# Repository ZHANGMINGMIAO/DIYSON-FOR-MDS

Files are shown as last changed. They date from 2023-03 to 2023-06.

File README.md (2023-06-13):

# DIYSON-FOR-MDS
复刻戴森台灯

电路连接框图 (2)
电路连接框图 1 (1)

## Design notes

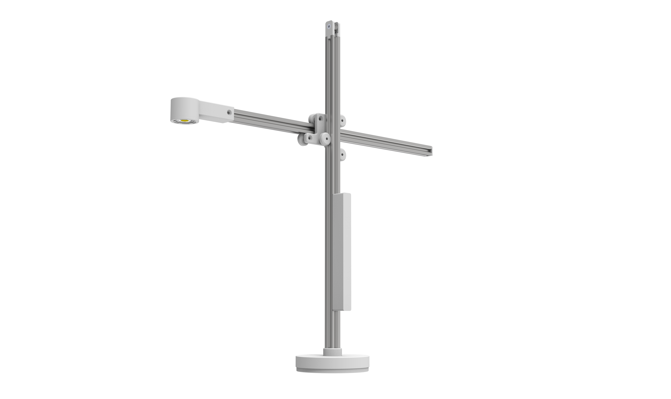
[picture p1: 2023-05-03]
DIYSON V2.png

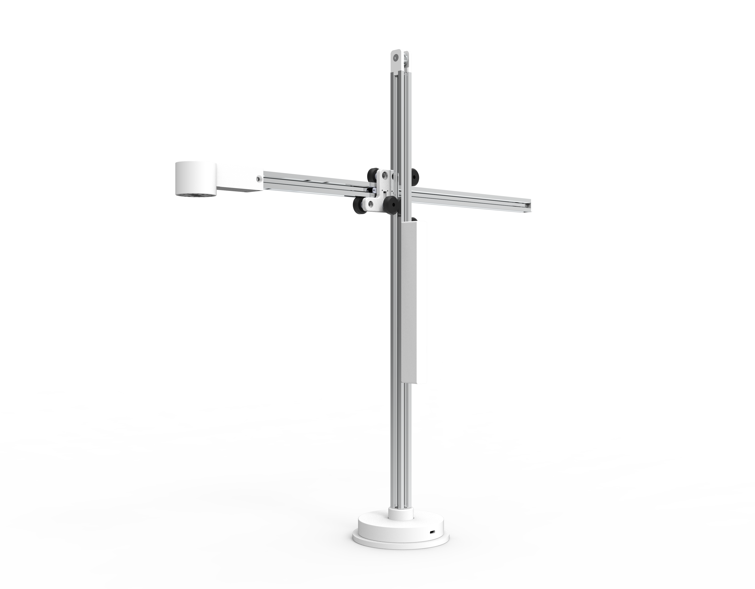
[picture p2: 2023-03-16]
Picture/untitled.3.png

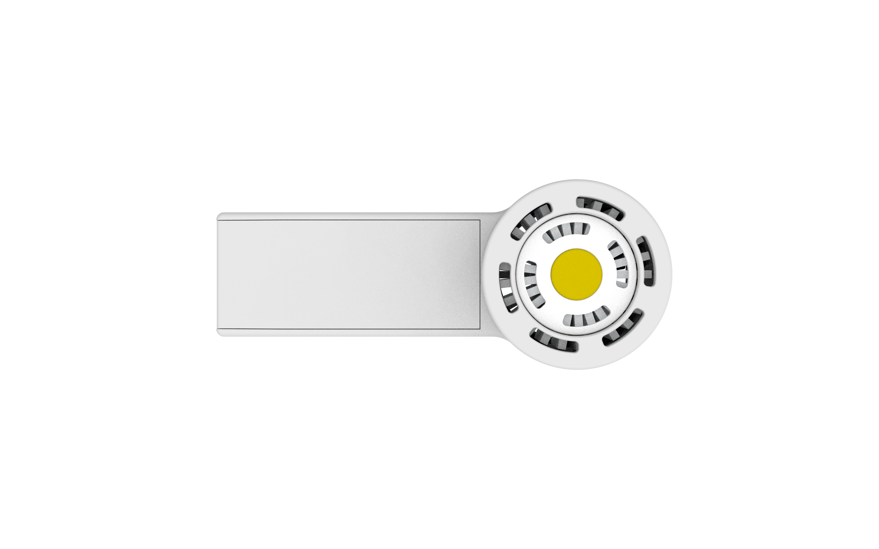
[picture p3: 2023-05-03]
Picture/灯头.7.png

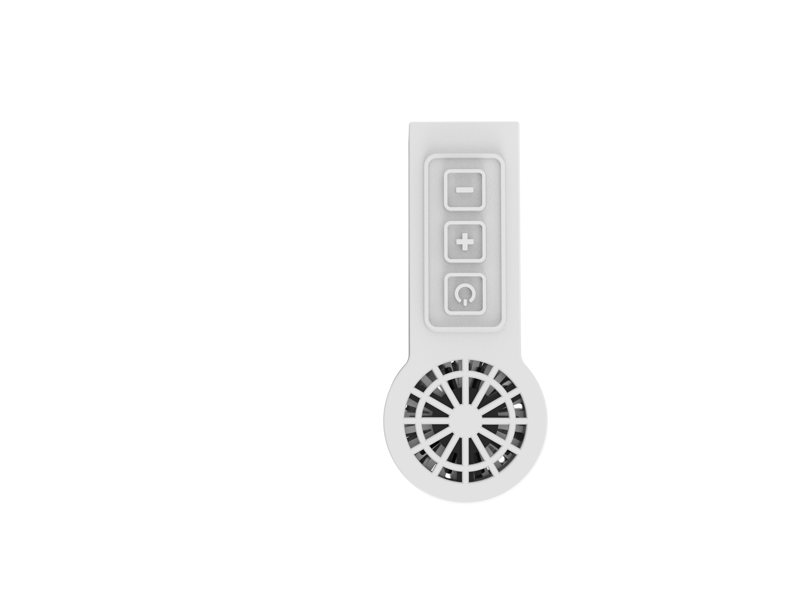
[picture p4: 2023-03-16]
Picture/untitled.5.png

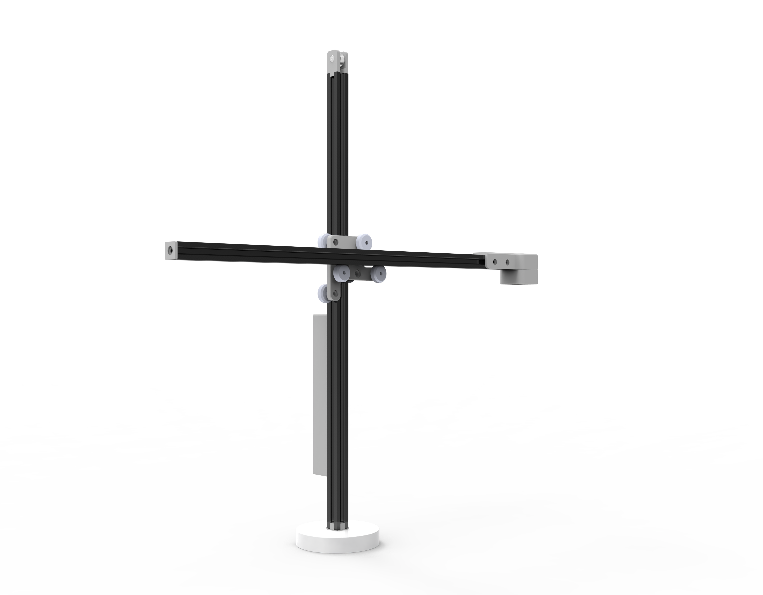
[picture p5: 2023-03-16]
Picture/DIYSON.1.png

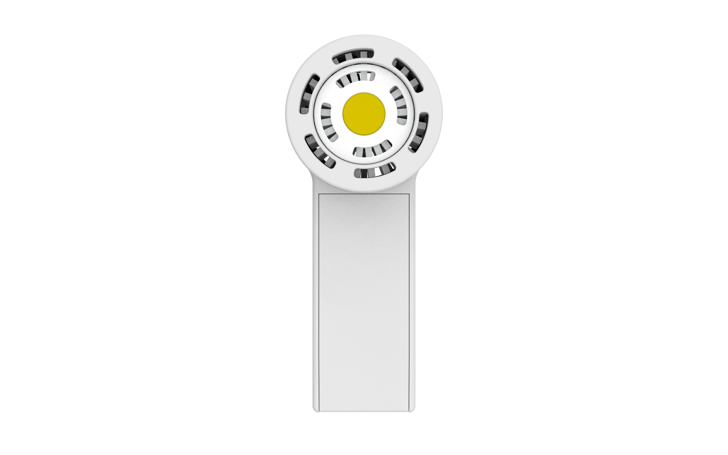
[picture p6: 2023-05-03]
Picture/灯头.9.png

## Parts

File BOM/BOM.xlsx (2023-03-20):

模块 | 元件类型 | 使用量 | 最低购买量 | 价格 | 购买链接
灯头 | CXA1507 4000K 36V 12W灯珠 | 1 | 1 | 7.4 | https://item.taobao.com/item.htm?spm=a1z0d.6639537/tb.1997196601.78.70727484ZepRym&id=674402505086
 | 科锐CREE光源支架COB CXA1507 | 1 | 1 | 1.27 | https://item.taobao.com/item.htm?spm=a1z0d.6639537/tb.1997196601.88.70727484ZepRym&id=38875948747
 | COB灯珠散热器 长度：2CM 直径3.8CM | 1 | 1 | 2.6 | https://item.taobao.com/item.htm?spm=a1z09.2.0.0.199f2e8dHjGU9n&id=651109740128&_u=j29jqmml1d36
 | LED透镜COB灯珠超薄透镜 35*12 | 1 | 1 | 0.8 | https://item.taobao.com/item.htm?spm=a1z09.2.0.0.199f2e8dHjGU9n&id=628937945428&_u=j29jqmml4557
 | 41*10MM圆形静音5V静音液压4CM风扇 3500rpm | 1 | 1 | 4.2 | https://item.taobao.com/item.htm?spm=a1z09.2.0.0.199f2e8dHjGU9n&id=690257082820&_u=j29jqmmlabdc
 | COB导热硅脂 | 1 | 1 | 1.4 | https://item.taobao.com/item.htm?spm=a1z09.2.0.0.199f2e8dHjGU9n&id=659749305136&_u=j29jqmmlfe73
 | 1.25mm 端子线 2P 双头(同向) | 5 | 10 | 1.95 | https://detail.tmall.com/item.htm?_u=j29jqmmle543&id=624732974819&spm=a1z09.2.0.0.199f2e8dHjGU9n
 | M2.6 自攻螺丝 M2.6 8mm | 2 | 20 | 5.3 | https://detail.tmall.com/item.htm?_u=j29jqmmla5ac&id=668672388165&spm=a1z09.2.0.0.199f2e8dHjGU9n
 | B-7000透明强力胶水 | 1 | 1 | 1.3 | https://item.taobao.com/item.htm?spm=a1z09.2.0.0.199f2e8dHjGU9n&id=651453833277&_u=j29jqmml6029
 | XL6019DC-DC可调升压电源模块 | 1 | 1 | 6.8 | https://detail.tmall.com/item.htm?abbucket=0&id=684608023988&ns=1&spm=a21n57.1.0.0.3d7b523cxRJ48t
 | TTP223触摸传感器触摸按键模块 | 1 | 1 | 2.29 | https://item.taobao.com/item.htm?spm=a1z09.2.0.0.199f2e8dHjGU9n&id=534945488372&_u=j29jqmml50a1
 | AMS1117-3.3V | 1 | 10 | 2.5 | https://item.taobao.com/item.htm?spm=a1z09.2.0.0.61952e8dVH444n&id=592499744957&_u=j29jqmml6740
连接架与底座 | 优质聚氨酯2GT白色同步带带宽6mm | 1 | 1 | 4.63 | https://item.taobao.com/item.htm?spm=a1z09.2.0.0.61952e8dVH444n&id=653571534103&_u=j29jqmmlf75c
 | 电池座手机电池连接器立式 2P 3.5H | 2 | 1 | 0.9 | https://item.taobao.com/item.htm?spm=a1z09.2.0.0.61952e8dVH444n&id=670722052173&_u=j29jqmml61cf
 | 绝缘柱塑料垫片 9*5*6 | 6 | 200 | 6.2 | https://detail.tmall.com/item.htm?_u=j29jqmml6f5f&id=631929683825&spm=a1z09.2.0.0.61952e8dVH444n
 | 3D打印机滑轮 导轨 张紧吊轮大轮 | 6 | 1 | 9 | https://item.taobao.com/item.htm?spm=a1z09.2.0.0.61952e8dVH444n&id=525708632172&_u=j29jqmmlcd35
 | 铁沙0.5/1/2/3/4mm钢砂脚架配重 2.0mm 1KG | 1 | 1 | 9.9 | https://item.taobao.com/item.htm?spm=a1z09.2.0.0.61952e8dVH444n&id=650785697009&_u=j29jqmmld822
 | t型螺母欧标铝型材弹片钢珠滑块 钢珠弹性20型-M5 (20个) 镀镍 | 2 | 20 | 6.8 | https://detail.tmall.com/item.htm?_u=j29jqmml949d&id=595406623302&spm=a1z09.2.0.0.61952e8dVH444n
 | 304不锈钢十字自攻螺丝沉头 M2*8 | 17 | 200 | 4.5 | https://detail.tmall.com/item.htm?_u=j29jqmmla5ac&id=668672388165&skuId=4991019363520
 | 304不锈钢十字自攻螺丝沉头 M2*12 | 6 | 200 | 5.3 | https://detail.tmall.com/item.htm?_u=j29jqmmla5ac&id=668672388165&skuId=4991019363520
 | 日本品牌高速电机静音轴承 206ZZ/P5铁封内径（mm） | 1 | 1 | 13.51 | https://detail.tmall.com/item.htm?_u=j29jqmml9dd1&id=590261283515&skuId=4705909512224
 | PD诱骗器触发QC4笔记本电源改装 12V升级版-PD诱骗器[PDT006] | 1 | 1 | 6.9 | https://item.taobao.com/item.htm?spm=a1z09.2.0.0.61952e8dVH444n&id=591914312564&_u=j29jqmml97ce
 | 2020V槽欧标铝型材2020v-slot铝材 60CM (注：两头攻牙M5螺纹) | 2 | 1 | 20 | https://item.taobao.com/item.htm?spm=a1z09.2.0.0.61952e8dVH444n&id=600111315253&_u=j29jqmmla28d
 | dc电源电源插座直流插头 DC-083插座 3.5-1.3MM | 1 | 5 | 3.5 | https://detail.tmall.com/item.htm?_u=j29jqmml3048&id=666895841322&spm=a1z09.2.0.0.61952e8dVH444n
 | 插头电源插座插头DC-005 DC插头 3.5*1.3 | 1 | 5 | 2.35 | https://detail.tmall.com/item.htm?_u=j29jqmml4f0e&id=667427411705&spm=a1z09.2.0.0.61952e8dVH444n
 | 通孔铜镶嵌注塑螺母预埋件 2*5*3.5 | 6 | 100 | 3 | https://buyertrade.taobao.com/trade/itemlist/list_bought_items.htm
 | 3D打印机配件2GT惰轮 16齿/20齿同步带轮H型皮带轮滑轮带宽6/10MM | 1 | 1 | 2.65 | https://item.taobao.com/item.htm?spm=a1z09.2.0.0.54c52e8dhvQr17&id=548682226471&_u=j29jqmml20ae
 | 12.9沉头内六角合金钢高强度 M5*10MM | 5 | 50 | 4.7 | https://detail.tmall.com/item.htm?_u=j29jqmmlafcb&id=677749487330&skuId=4860920044837
 | 12.9沉头内六角合金钢高强度 M5*25MM | 1 | 50 | 7.8
 | 12.9沉头内六角合金钢高强度 M5*30MM | 6 | 20 | 4.1
 | 304不锈钢尼龙防松螺母 M5 | 6 | 50 | 4.4 | https://detail.tmall.com/item.htm?id=606065145380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
PCB | 触点连接件 厚度1mm 白色阻焊 | 2 | 2 | 20 | 嘉立创PCB，打样文件在PCB文件夹
 | 58.5cm*1.1cm 滑动导轨 PCB厚度 1.2mm 白色阻焊 | 3 | 3 | 68 | 捷配PCB，打样文件在PCB文件夹
3D打印耗材 | 彩格PLA耗材3D打印机材料可定制 PLA 1.75 白色1KG | 1 | 1 | 56.8 | https://detail.tmall.com/item.htm?_u=j29jqmml000b&id=555578272810&spm=a1z09.2.0.0.61952e8dVH444n
 |  |  | 总计： | 302.75

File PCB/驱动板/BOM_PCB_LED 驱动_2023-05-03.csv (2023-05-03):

ID | Name | Designator | Footprint | Quantity | Manufacturer Part | Manufacturer | Supplier | Supplier Part | Price
1 | 22uf 50V | C1,C2,C5,C6 | C0603 | 4 |  |  | LCSC | C94073 | 0.0267
2 | 100nf 50V | C8,C10 | C0603 | 2 |  |  | LCSC | C5199872 | 0.042
3 | 0.51R | R5,R2 | R0603 | 2 |  |  | LCSC | C2073794 | 3.18
4 | 2543U-104CNG1SNT01 | H2 | HDR-TH_4P-P2.00-V-F | 1 | 2543U-104CNG1SNT01 | 华宇创 | LCSC | C350271 | 0.6401
5 | 100nf 50V | C3,C4,C9,C12 | C0603 | 4 |  |  | LCSC | C94073 | 0.0267
6 | 47uF 50V | C7,C15 | CAP-SMD_BD6.3-L6.6-W6.6-LS7.4-FD | 2 |  |  | LCSC | C688950 | 0.8894
7 | 22uf 50V | C13,C16 | C0603 | 2 |  |  | LCSC | C2762594 | 0.3109
8 | 47UH | L1,L2 | IND-SMD_L7.3-W6.6_MHCI06030 | 2 |  |  | LCSC | C5349685 | 0.4365
9 | 4.7UH | L3 | IND-SMD_L10.0-W10.0_MS1040-XX | 1 |  |  | LCSC | C436485 | 1.087
10 | 47K | R7,R9 | R0603 | 2 |  |  | LCSC | C115320 | 0.0049
11 | NC | U6 | HDR-TH_2P-P2.54-V-M-1 | 1 | 单排2.54*2 | null | LCSC | C9900016158
12 | AO3415AL | Q2 | SOT-23-3_L2.9-W1.6-P1.90-LS2.9-BL | 1 | AO3415AL | AOS | LCSC | C181094 | 0.2267
13 | TPS54202DDCR | U4 | SOT-23-6_L2.9-W1.6-P0.95-LS2.8-BR | 1 | TPS54202DDCR | Texas Instruments | LCSC | C191884 | 1.4653
14 | 10kΩ | R10 | RES-ADJ-SMD_3P-L3.0-W3.8-P1.75-BR | 1 | TC33X-2-103E | BOURNS | LCSC | C128547 | 0.557
15 | 100k | R11 | R0603 | 1 |  |  | LCSC | C115320 | 0.0049
16 | 20k | R13 | R0603 | 1 |  |  | LCSC | C125934 | 0.013
17 | 2.7k | R14 | R0603 | 1 |  |  | LCSC | C13167 | 0.0064
18 | 100nf | C14 | C0603 | 1 |  |  | LCSC | C94073 | 0.0267
19 | 10uH | L4 | IND-SMD_L4.0-W4.0_XFL4020-102MEB | 1 | YSPI0530-100M | YJYCOIN | LCSC | C351099 | 0.9762
20 | 56k | R8 | R0603 | 1 |  |  | LCSC | C23206 | 0.0068
21 | SS34BG | D4,D5,D1 | SMB_L4.6-W3.6-LS5.3-RD | 3 | SS34BG | SHIKUES(时科) | LCSC | C2891718 | 0.1679
22 | 3k | R4,R3 | R0603 | 2 |  |  | LCSC | C125893 | 0.013
23 | 1k | R6,R1 | R0603 | 2 |  |  | LCSC | C2982978 | 0.0119
24 | XL6019E1 | U3 | TO-263-5_L10.2-W9.9-P1.70-LS14.4-TL | 1 | XL6019E1 | XLSEMI(芯龙) | LCSC | C73018 | 3.51
25 | HI7003 | U1,U2 | SOP-8 | 2 | HI7003 | Hichips(智芯) | LCSC | C2830170 | 2.97

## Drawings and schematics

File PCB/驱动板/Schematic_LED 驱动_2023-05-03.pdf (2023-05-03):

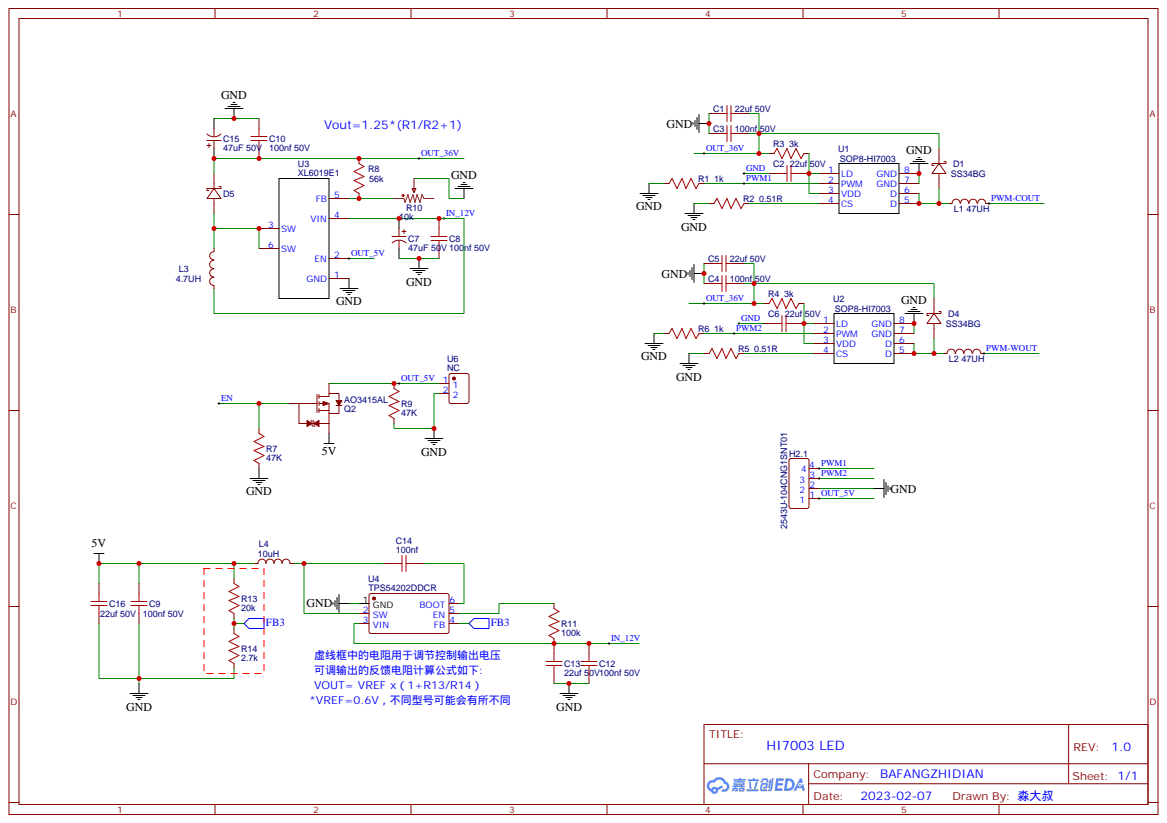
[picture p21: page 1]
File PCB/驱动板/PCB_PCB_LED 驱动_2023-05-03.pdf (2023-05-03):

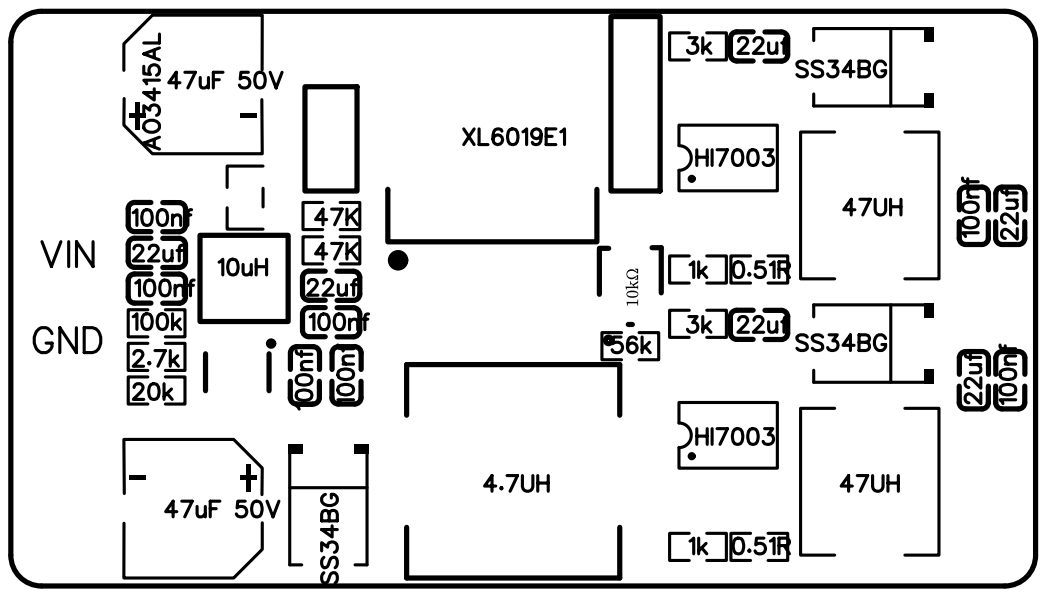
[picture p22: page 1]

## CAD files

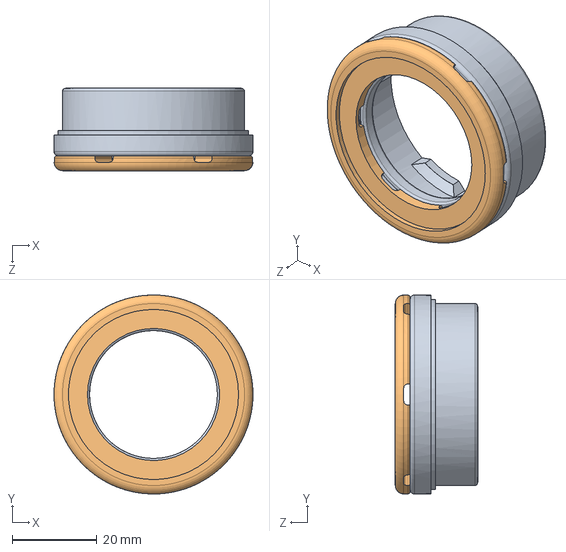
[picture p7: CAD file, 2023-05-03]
slprt/灯头柔光.SLDASM
47.0 x 47.0 x 19.5 mm
灯头盖 - 副本
柔光盖

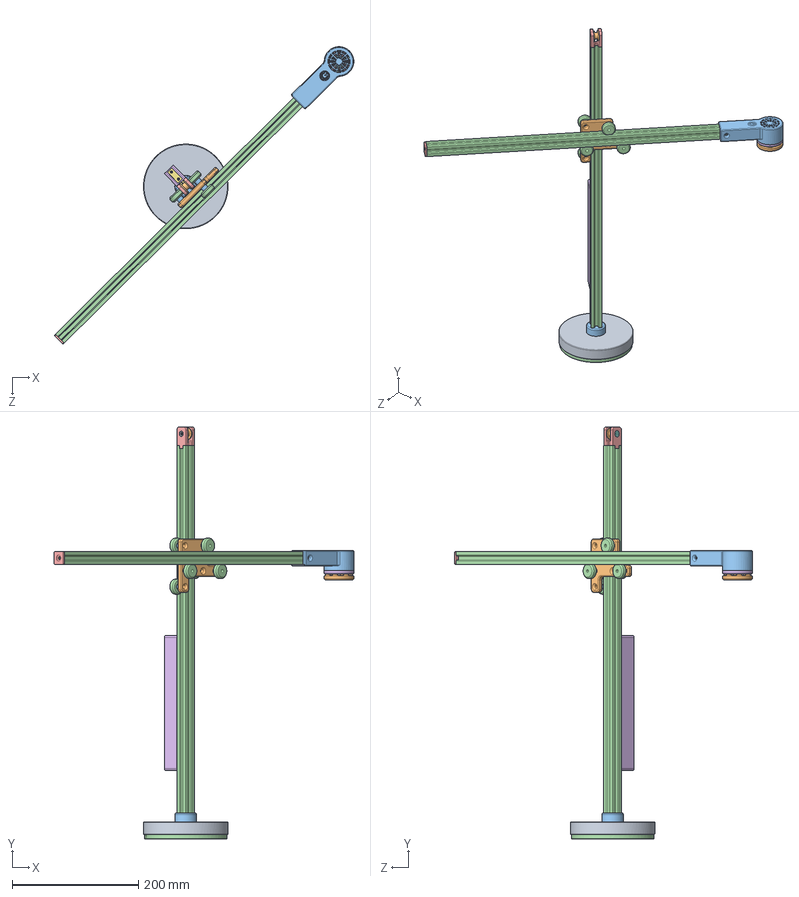
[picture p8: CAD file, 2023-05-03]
slprt/DIYSON.SLDASM
475.2 x 653.2 x 472.0 mm
底座
6206ZZ轴承
Base
2020V 铝型材 x 2
Pulley Mount
Coutnterweight Enclosure
Flex Tab x 2
螺丝^DIYSON
螺母^DIYSON
2GT多轮
隔离柱 x 6
Big wheel x 6
End Cap
Counterweight Belt Clip
Coutnterweight Lid
Base2
DC
Carriage
灯头42
风扇3010
散热器3820
灯头盖
零件2^灯头
零件3^灯头
零件4^灯头
底座盖板2
USB_Type-C

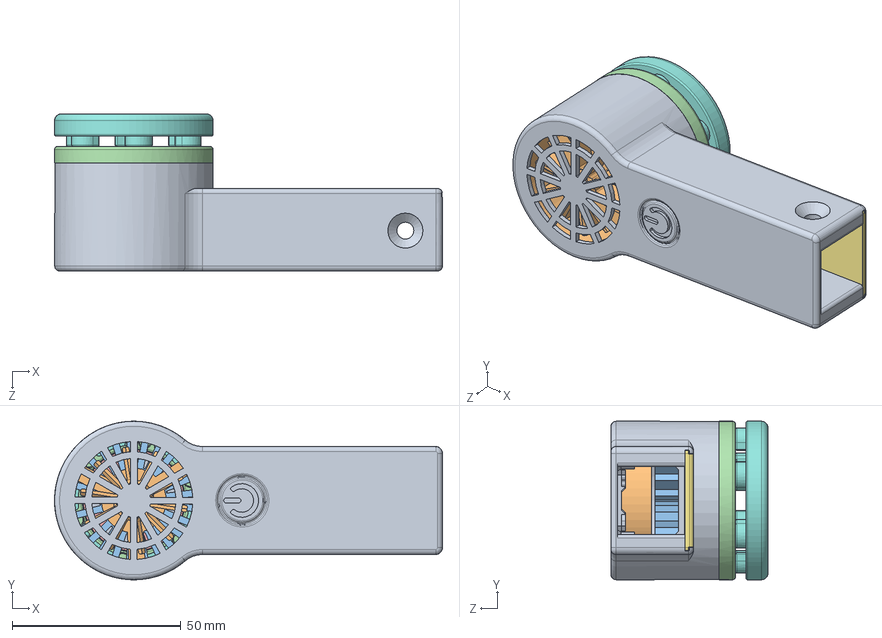
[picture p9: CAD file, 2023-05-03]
slprt/灯头.SLDASM
115.0 x 47.0 x 46.6 mm
灯头42
风扇3010
散热器3820
灯头盖
零件2^灯头
零件3^灯头
零件4^灯头

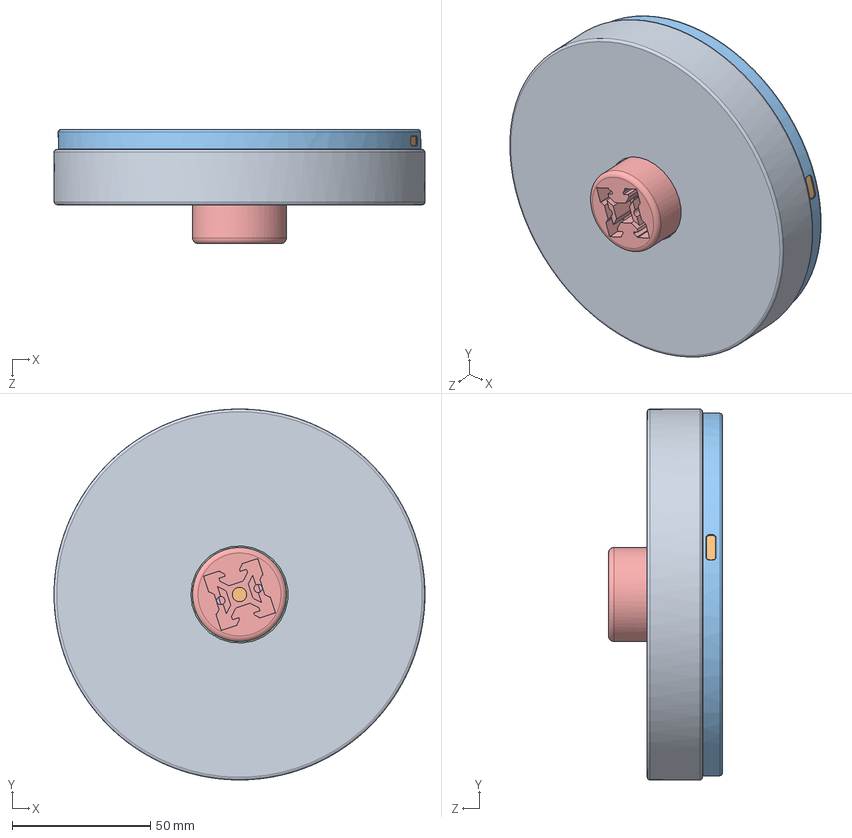
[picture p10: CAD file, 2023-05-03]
slprt/底座.SLDASM
134.0 x 134.0 x 41.2 mm
底座
底座盖板2
6206ZZ轴承
Base
Base2

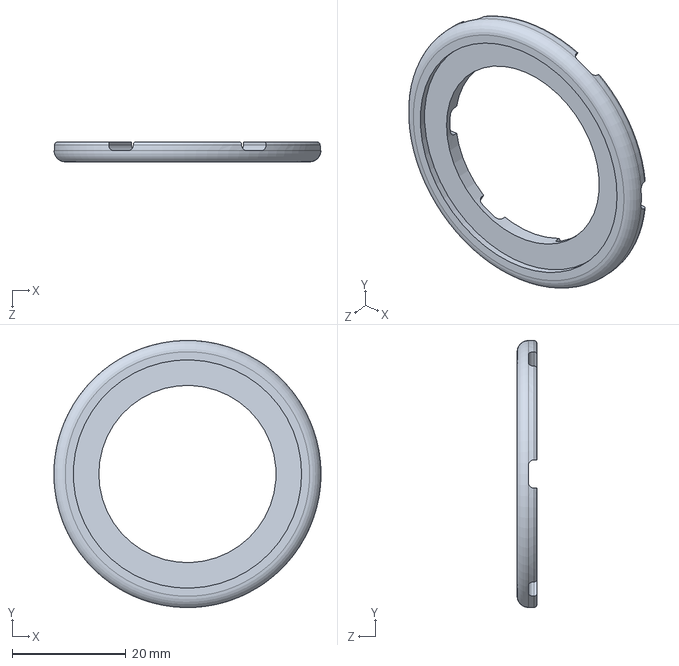
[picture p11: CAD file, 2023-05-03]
slprt/柔光盖.sldprt
47.0 x 47.0 x 3.50 mm

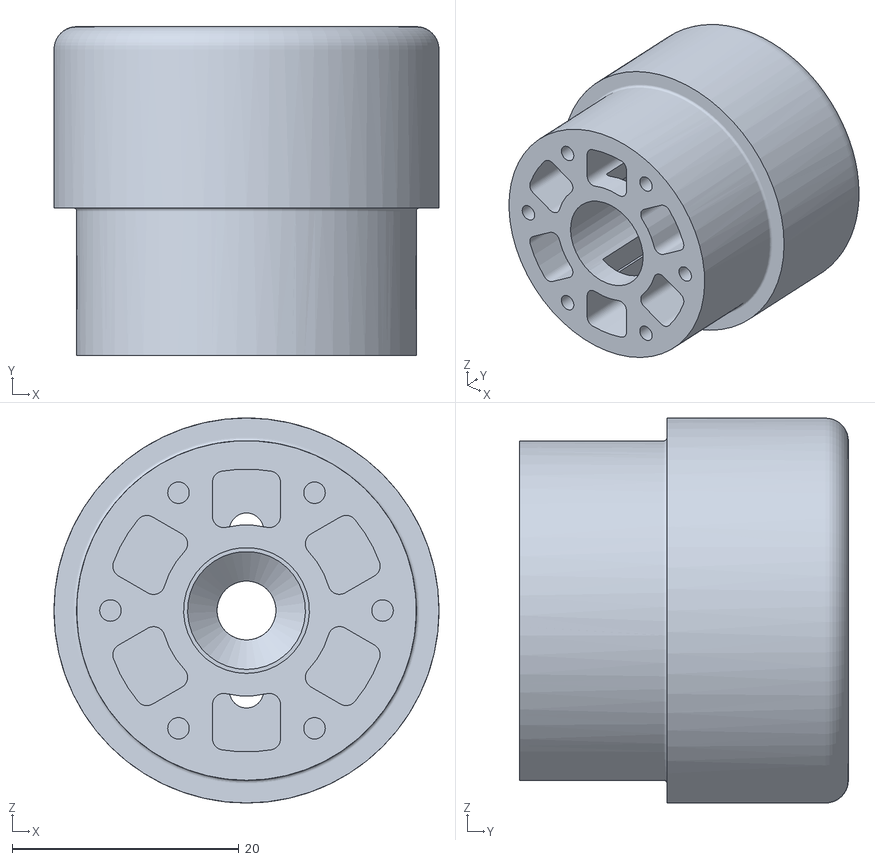
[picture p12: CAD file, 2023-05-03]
STL/Base.STL
34.0 x 29.0 x 34.0

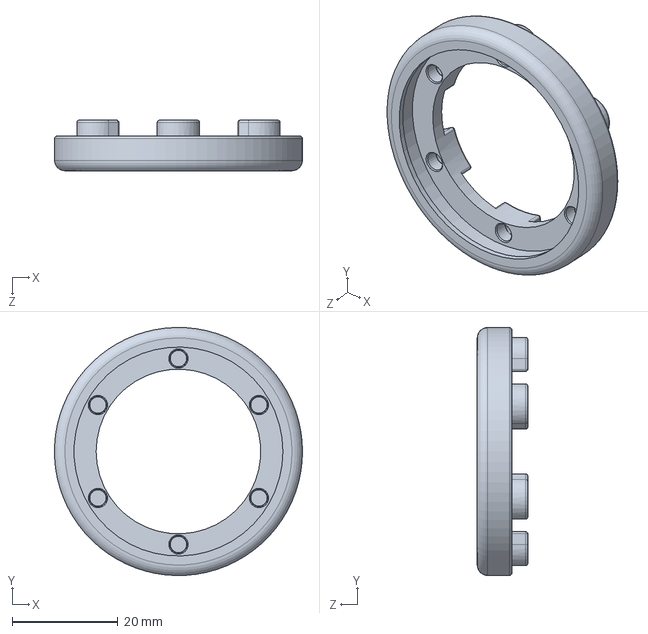
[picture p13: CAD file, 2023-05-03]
slprt/蜂窝盖.sldprt
47.0 x 47.0 x 9.60 mm

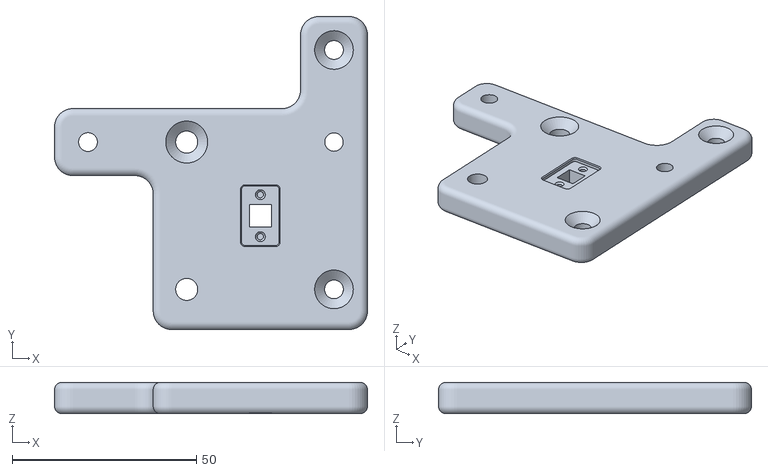
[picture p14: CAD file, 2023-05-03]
STL/Carriage.STL
85.0 x 85.0 x 8.50

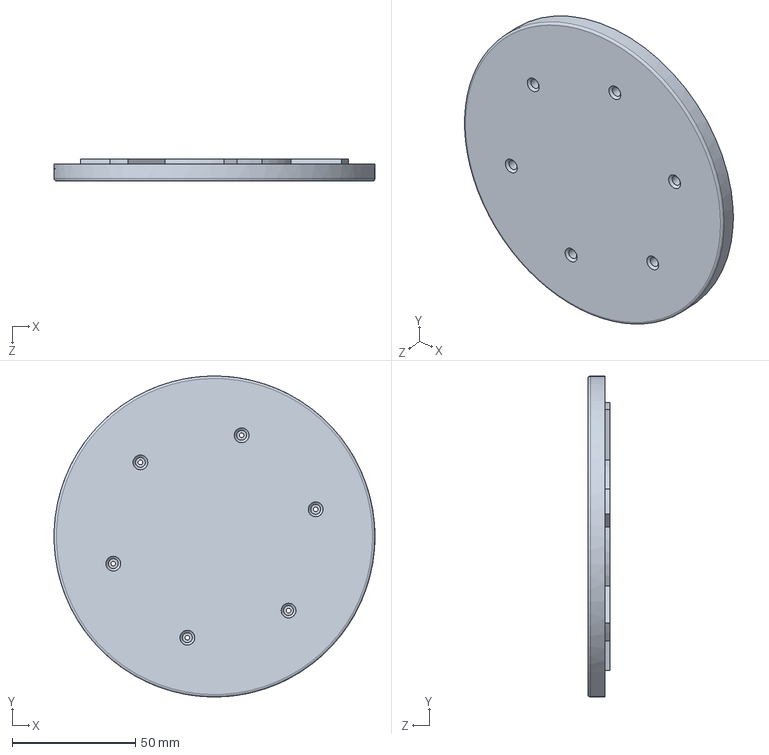
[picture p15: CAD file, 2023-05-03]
slprt/底座盖板.sldprt
130.0 x 130.0 x 9.00 mm

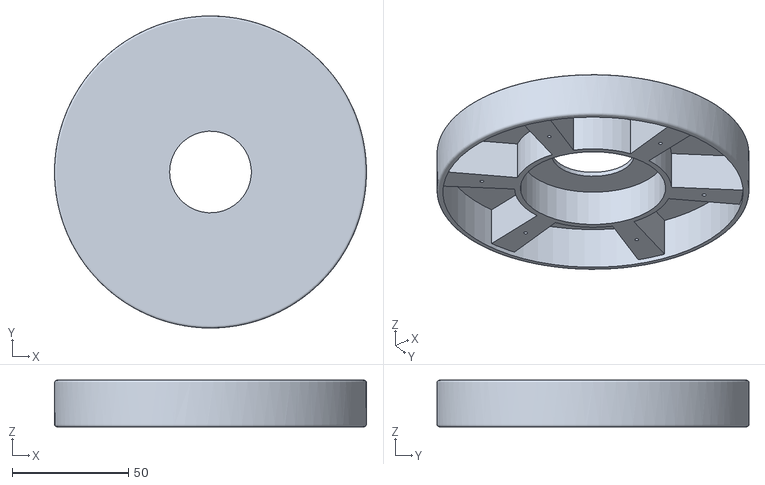
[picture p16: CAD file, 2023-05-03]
STL/底座.STL
134.0 x 134.0 x 20.0

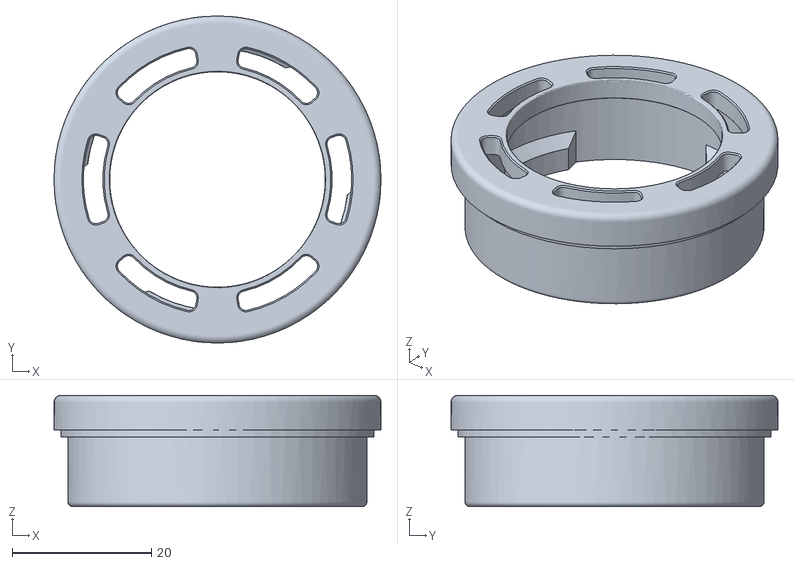
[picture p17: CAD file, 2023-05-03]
STL/灯头盖.STL
47.0 x 47.0 x 16.0

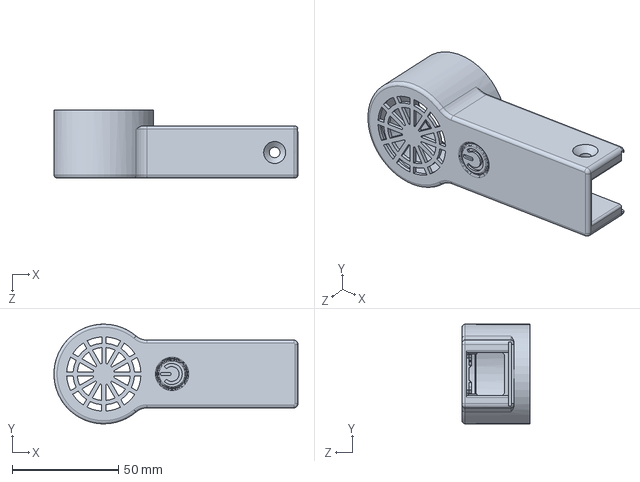
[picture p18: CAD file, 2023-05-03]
slprt/灯头42.sldprt
115.0 x 47.0 x 32.0 mm

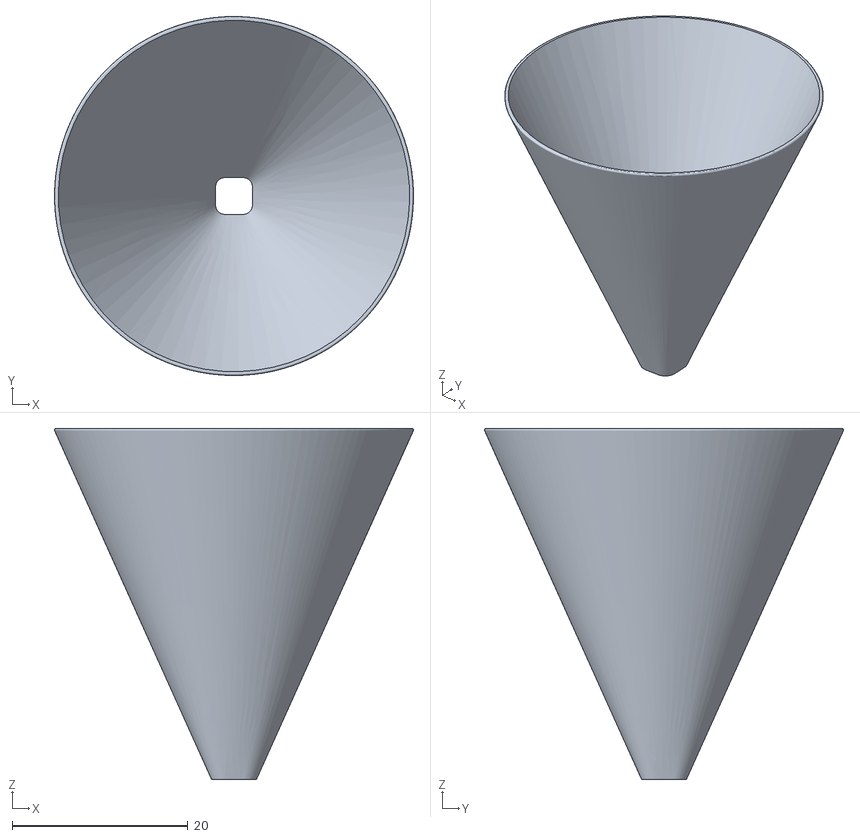
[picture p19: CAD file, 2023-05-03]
STL/配重配件.STL
40.9 x 40.9 x 40.0

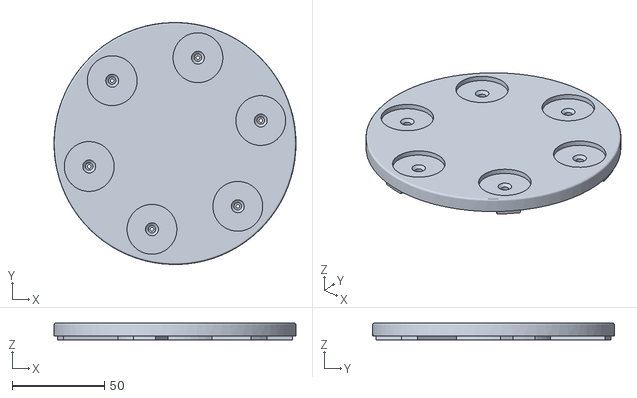
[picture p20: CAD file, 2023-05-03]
STL/底座盖板.STL
131.0 x 131.0 x 9.20

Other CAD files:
slprt/配重配件.SLDPRT
STL/Coutnterweight Enclosure.STL
STL/灯头底盖.STL
slprt/Carriage2.SLDPRT
STL/Base2.STL
STL/Carriage2.STL
STL/Counterweight Belt Clip.STL
STL/Coutnterweight Lid.STL
STL/End Cap.STL
STL/Flex Tab.STL
STL/Pulley Mount.STL
STL/柔光盖.STL
STL/灯头.STL
STL/蜂窝盖.STL
slprt/2020V 铝型材.sldprt
slprt/2GT多轮.sldprt
slprt/6206ZZ轴承.SLDPRT
slprt/Base.SLDPRT
slprt/Base2.sldprt
slprt/Big wheel.sldprt
slprt/Carriage.SLDPRT
slprt/Counterweight Belt Clip.SLDPRT
slprt/Coutnterweight Enclosure.SLDPRT
slprt/Coutnterweight Lid.SLDPRT
slprt/DC.SLDPRT
slprt/End Cap.SLDPRT
slprt/Flex Tab.SLDPRT
slprt/Pulley Mount.SLDPRT
slprt/底座.sldprt
slprt/底座盖板2.sldprt
slprt/按键盖板.sldprt
slprt/散热器3820.SLDPRT
slprt/灯头底盖.sldprt
slprt/灯头盖 - 副本.sldprt
slprt/灯头盖.sldprt
slprt/隔离柱.sldprt
slprt/风扇3010.SLDPRT
